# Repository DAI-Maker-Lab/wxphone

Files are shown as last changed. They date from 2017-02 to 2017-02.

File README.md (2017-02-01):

# wxPhone
wxPhone is an open-source weather station design based on the Seeeduino Stalker V3, Adafruit FONA and BME280 breakout boards, and Ambient Data Systems weather meters. It is a work in progress and is presently being field tested in Silver Spring, Maryland in the United States and Malang, Indonesia.

The design will not work with the newer Stalker V3.1 boards; among other issues they do not supply enough current to power the FONA. This is a problem. The next iteration will use a different microcontroller and a configuration that allows the BME280 board to be mounted separately from the other electronics, so that only the BME280 is exposed to the air.

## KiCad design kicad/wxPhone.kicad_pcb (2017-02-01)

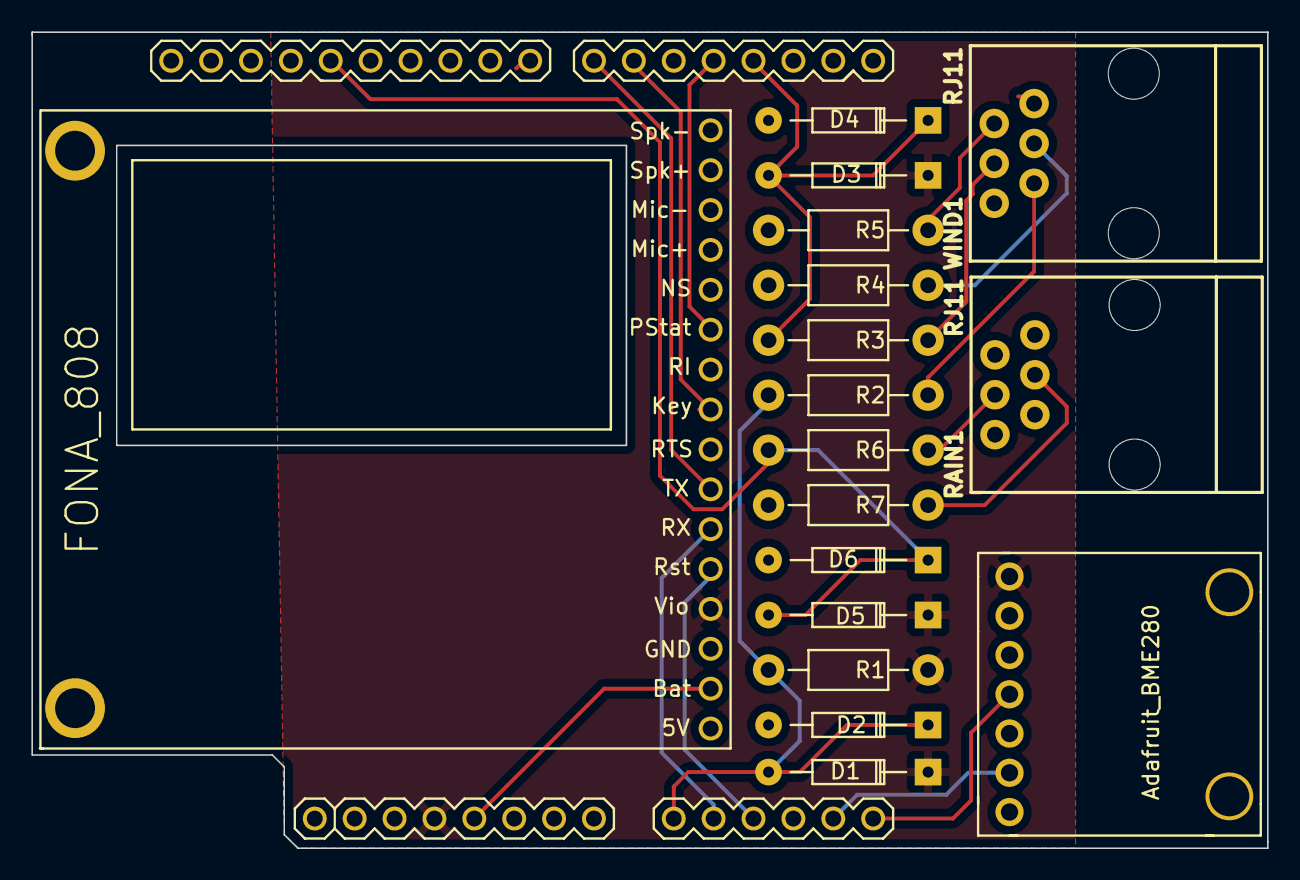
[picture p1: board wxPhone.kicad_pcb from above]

Board: 2 copper layers, 78.7 x 52.0 mm, 18 parts (0 on the bottom side), 19 nets.

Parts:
D1, D2, D3, D4, D5, D6: DIODE; Diode_DO-35_SOD27_Horizontal_RM10
R1: 4.7K; Resistor_Horizontal_RM10mm
R2, R3, R4, R5, R6, R7: 1K; Resistor_Horizontal_RM10mm
RAIN1: RJ11; RJ11-6
SHIELD1: ARDUINO_SHIELD; ARDUINO
U1: Adafruit_BME280
U2: FONA_808
WIND1: RJ11; RJ11-6

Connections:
3V3: D1.K, D3.K, D5.K, R1.1, SHIELD1.3V3, U1.VIN, U2.4
GND: D2.A, D4.A, D6.A, R4.2, R5.2, R7.2, SHIELD1.GND1, U1.GND, U2.3
unnamed: R2.1, WIND1.2
unnamed: R3.1, WIND1.3
unnamed: R4.1, WIND1.4
unnamed: R5.1, WIND1.5
unnamed: R6.1, RAIN1.3
unnamed: R7.1, RAIN1.4
unnamed: SHIELD1.4, U2.11
unnamed: SHIELD1.6, U2.9
unnamed: SHIELD1.7, U2.7
unnamed: SHIELD1.AD4, U1.SDI
unnamed: SHIELD1.AD5, U1.SCK
RAIN: D5.A, D6.K, R6.2, SHIELD1.13
RST: SHIELD1.AD2, U2.5
RX: SHIELD1.AD1, U2.6
VCC+: SHIELD1.5V, U2.2
WDIR: D1.A, D2.K, R1.2, R2.2, SHIELD1.AD0
WSPEED: D3.A, D4.K, R3.2, SHIELD1.3

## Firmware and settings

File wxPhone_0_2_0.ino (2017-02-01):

#define VERSION "0.2.0"      //  Version number

//  Customize these items for each installation
// - - - - - - - - - - - - - - - - - - - - - - - - - - - - - - - - - - - - - - - 
#define PUBLIC_KEY "dZ9j1JqgEwtqp8QGyQLn"      //  Public key for phant stream
#define PRIVATE_KEY "eEJjA1V5XxTD5mlMxl0B"    //  Private key for phant stream
#define INITIAL_LAT 39.020000
#define INITIAL_LON -77.050000
#define INITIAL_ALT 122

#define UTCOFFSET -5        //  Local standard time variance from UTC
#define XBEEWINDOWSTART 8   //  Hour to turn on XBee for programming window
#define XBEEWINDOWEND 20    //  Hour to turn off XBee
#define INTERVAL 15         //  Number of minutes between readings
#define BEEPASSWORD "XBEE_PASSWORD"  //  Password to turn on XBee by SMS
// - - - - - - - - - - - - - - - - - - - - - - - - - - - - - - - - - - - - - - - 



#include <Adafruit_BME280.h>    //  Pressure/temp/humidity sensor
#include <Adafruit_FONA.h>      //  For Adafruit FONA module
#include <Adafruit_Sensor.h>    //  Adafruit unified sensor abstraction layer
#include <DS1337.h>             //  For the Stalker's real-time clock (RTC)
#include <ss_no_int3.h>         //  SoftwareSerial with pin-change conflict removed
#include <Sleep_n0m1.h>         //  Sleep library
#include <SPI.h>
#include <Wire.h>               //  I2C needed for sensors



#define RTCINT 0                //  RTC interrupt number
#define WDIR A0                 //  Wind direction from vane
#define FONA_RX A1              //  FONA RX pin
#define FONA_RST A2             //  FONA reset pin
#define WSPEED 3                //  Wind speed interrupt pin
#define FONA_TX 7               //  FONA TX pin
#define BEEPIN 5                //  XBee power pin
#define FONA_KEY 6              //  FONA on/off pin
#define FONA_PS 4               //  FONA power status pin
#define RAIN 13                 //  Rain gauge interrupt pin

long lastWindCheck = 0;
volatile long lastWindIRQ = 0;
volatile byte windClicks = 0;
volatile float rainMinute[60];      //  60 floating numbers to keep track of 60 minutes of rain

//  Weather values
char* wind_dir;                    //  Instantaneous wind direction
float wind_speed = 0;              //  km/h instantaneous wind speed
float temp = 0;                    //  temperature C
float humidity = 0;                //  %
float pressure = 0;
float rainHourly[24];              //  24 floats to track the last 24 hours of rain
float rain_today = 0.00;           //  Rain since midnight (mm)

volatile unsigned long raintime, rainlast, raininterval, rain;

boolean dataSent = false;

byte beeShutoffHour = 0;        //  Hour to turn off manual power to XBee
byte beeShutoffMinute = 0;      //  Minute to turn off manual power to XBee
boolean smsPower = false;       //  Manual XBee power flag

/* We will create variables to hold  values for the time and date from the RTC. */
int currentHour;    
byte currentMinute;     
byte currentDay;
byte currentMonth;
int currentYear;
DateTime now;

float latitude = INITIAL_LAT;
float longitude = INITIAL_LON;
float altitude = INITIAL_ALT;

ss_no_int3 fonaSerial = ss_no_int3 (FONA_TX, FONA_RX);
Adafruit_FONA fona = Adafruit_FONA (FONA_RST);

Adafruit_BME280 bme;              //  Instantiate BME280 sensor object
DS1337 RTC;                       //  Instantiate real-time clock (RTC) object
Sleep sleep;                      //  Instantiate sleep object



void pciSetup()
{
        //  Setup pin change interrupt for rain pin
        *digitalPinToPCMSK(RAIN) |= bit (digitalPinToPCMSKbit(RAIN));  //   Enable pin
        PCIFR  |= bit (digitalPinToPCICRbit(RAIN)); //    Clear any outstanding interrupt
        PCICR  |= bit (digitalPinToPCICRbit(RAIN)); //    Enable interrupt for the group
}



static void rtcIRQ()
{
        RTC.clearINTStatus();   //  Wake from sleep and clear the RTC interrupt
}



ISR (PCINT0_vect)                    //  Count rain gauge bucket tips as they occur
{
        raintime = millis();       
        raininterval = raintime - rainlast;  //  calculate interval between this and last event
      
        if (raininterval > 40)  //  ignore switch-bounce glitches less than 10mS after initial edge
        {
                rain_today += 0.2794;                //  Each dump is 0.2794mm of water
                rainMinute[currentMinute] += 0.2794; //  Increase this minute's amount of rain
                rainlast = raintime;                 //  Set up for next event
        }
}



static void wspeedIRQ()      //  Activated by the magnet in the anemometer (2 ticks per rotation)
{
        if (millis() - lastWindIRQ > 10)  //  Ignore switch-bounce glitches less than 10ms
        {
                lastWindIRQ = millis();   
                windClicks++;             //  Each click per second represents 2.40264 km/h of wind
        }
}



void setup()
{
        Wire.begin(); //  Begin the I2C interface
        RTC.begin();  //  Begin the RTC        
        Serial.begin (57600);
        Serial.print (F("wxPhone version "));
        Serial.print (VERSION);
        Serial.print (F(" "));
        Serial.print (__DATE__);    //  Compile data and time helps identify software uploads
        Serial.print (F(" "));
        Serial.println (__TIME__);

        analogReference (INTERNAL); 

        Serial.print (F("Startup voltage "));
        Serial.println (analogRead (A7) * 6.4);   //  Convert ADC reading to voltage
        
        pinMode (BEEPIN, OUTPUT);
        pinMode (FONA_KEY, OUTPUT);
        pinMode (FONA_PS, INPUT);       
        pinMode (FONA_RX, OUTPUT);
        pinMode (WSPEED, INPUT_PULLUP);
        pinMode (RAIN, INPUT_PULLUP);
        pinMode (WDIR, INPUT);


        /*   If the voltage at startup is less than 3.5V, we assume the battery died in the field
         *   and the unit is attempting to restart after the panel charged the battery enough to
         *   do so. However, running the unit with a low charge is likely to just discharge the
         *   battery again, and we will never get enough charge to resume operation. So while the
         *   measured voltage is less than 3.5V, we will put the unit to sleep and wake once per 
         *   hour to check the charge status.
         */

        while (analogRead (A7) < 547)   
        {
                Serial.print (F("Battery voltage is only "));
                Serial.print (analogRead (A7) * 6.4);
                Serial.print (F("mV. Sleeping to save power while panel recharges..."));
                Serial.flush();
                digitalWrite (BEEPIN, HIGH);      //  Make sure XBee is powered off
                RTC.enableInterrupts (EveryHour); //  We'll wake up once an hour
                RTC.clearINTStatus();             //  Clear any outstanding interrupts
                attachInterrupt (RTCINT, rtcIRQ, FALLING);
                interrupts();
                sleep.pwrDownMode();                    //  Set sleep mode to Power Down
                sleep.sleepInterrupt (RTCINT, FALLING); //  Sleep; wake on falling voltage on RTC pin
        }

        digitalWrite (FONA_KEY, HIGH);       //  Initial state for key pin

        //  We will use the FONA to get the current time to set the Stalker's RTC
        fonaOn();
        clockSet();
        
        //  Delete any accumulated SMS messages to avoid interference from old commands
        fona.sendCheckReply (F("AT+CMGF=1"), F("OK"));            //  Enter text mode
        fona.sendCheckReply (F("AT+CMGDA=\"DEL ALL\""), F("OK")); //  Delete all SMS messages

        gpsFix();
        
        fonaOff();

        pciSetup();
        RTC.enableInterrupts (EveryMinute);  //  RTC will interrupt every minute
        RTC.clearINTStatus();                //  Clear any outstanding interrupts
        attachInterrupt (RTCINT, rtcIRQ, FALLING);

        now = RTC.now();    //  Get the current time from the RTC
        
        //  We'll keep the XBee on for an hour after startup to assist installation
        if (now.hour() == 23)
        {
                beeShutoffHour = 0;
        }
        else
        {
                beeShutoffHour = (now.hour() + 1);
        }
        beeShutoffMinute = now.minute();

        Serial.print (F("XBee powered on until at least "));
        Serial.print (beeShutoffHour);
        Serial.print (F(":"));
        Serial.println (beeShutoffMinute);
        Serial.flush();
        smsPower = true; 
        
        if (bme.begin() == false) 
        {
                Serial.println(F("Could not find a valid BME280 sensor; check wiring."));
                while (1);
        }
        else
        {
                Serial.print (F("Humidity: "));
                Serial.println (bme.readHumidity());
                Serial.print (F("Local pressure: "));
                Serial.println (bme.readPressure() / 100);
                Serial.print (F("Sea level pressure: "));
                getPressure();
                Serial.println (pressure);
                Serial.print (F("Temperature: "));
                Serial.println (bme.readTemperature());
        }

        analogReference (DEFAULT);
      
        // attach external interrupt pins to IRQ functions
        //attachInterrupt(0, rainIRQ, FALLING);
        attachInterrupt(1, wspeedIRQ, FALLING);
      
        interrupts();      
}



void loop()
{
        now = RTC.now();   //  Get the current date/time
        
        if(currentMinute != now.minute())
        {
                currentMinute = now.minute(); 
                rainMinute[currentMinute] = 0; 
                
                if(currentMinute == 0)    //  Every hour, update the hourly rain count
                {
                        int lastHour;
                        currentHour = now.hour();
                        
                        if(currentHour == 0)
                        {
                                lastHour = 23;
                        }
                        else
                        {
                                lastHour = currentHour - 1;
                        }
                        
                        rainHourly[lastHour] = 0;
                        
                        for(int i = 0 ; i < 60 ; i++)
                        {
                                rainHourly[lastHour] += rainMinute[i];
                        }
                }
        }

        //  We will turn on the XBee radio for programming only within a specific
        //  window to save power
        if (now.hour() >= XBEEWINDOWSTART && now.hour() <= XBEEWINDOWEND)
        {
                digitalWrite (BEEPIN, LOW);
        }
        else
        {
                //  If the XBee power was turned on by SMS, we'll check to see if 
                //  it's time to turn it back off
                if(smsPower == true && now.hour() < beeShutoffHour)
                {
                        digitalWrite (BEEPIN, LOW);
                }
                else
                {
                        if(smsPower == true && now.hour() == beeShutoffHour && now.minute() < beeShutoffMinute)
                        {
                                digitalWrite (BEEPIN, LOW);
                        }
                        else
                        {
                                if (smsPower == true)
                                {
                                          Serial.println (F("Turning XBee off..."));
                                          Serial.flush();
                                          wait (500);
                                }

                                digitalWrite (BEEPIN, HIGH);
                                smsPower = false;
                        }
                }
        }

        //  If the sent flag is up and this is not an upload minute, lower it
        if(currentMinute % INTERVAL != 0 && dataSent == true)  
        {
                dataSent = false;
        }
        
        //  Check to see if upload is necessary; if so, take readings and send them
        if(currentMinute % INTERVAL == 0 && dataSent == false)
        {       
                Serial.println(F("Upload minute; will boot FONA."));
  
                currentHour = now.hour();      
                currentDay = now.date();       
                currentMonth = now.month();
                currentYear = now.year();
        
                calcWeather();  //  Poll the various sensors
        
                fonaOn();     //  Start the Fona
        
                //  We will attempt to upload data to the cloud. If the attempt fails,
                //  we will restart the Fona and try again for up to three attempts.
            
                byte sendAttempts = 0;    //  Reset the counter
            
                while(dataSent == false && sendAttempts <= 2)
                {
                        sendAttempts++;   //  Increment attempt counter
                  
                        if(sendWeather() == false)  //  If upload appears to fail...
                        {
                                Serial.println(F("Upload failed. Restarting Fona."));
                                fonaOff();   //  ...shut the FONA off.
                                delay(5000);      //  Give the FONA a moment
                                fonaOn();         //  Reboot.
                                dataSent = false; //  Ensure flag is down
                        }
                        else
                        {
                                dataSent = true;
                        }
                }
        
                if(currentHour == 0 && currentMinute == 0)  //  At midnight, after upload...
                {
                        rain_today = 0.00;       // ...zero out the day's rain total...
                        clockSet();              // ...and set the time again -- the RTC loses about
                                                 // one minute every six days.
                        if (latitude == INITIAL_LAT)  //  If we never successfully got a GPS fix...
                        {
                                gpsFix();             //  ...try again.
                        }
                }

                fonaOff();           //  Shut down the FONA to save power
        }

        sleep.pwrDownMode();                    //  Set sleep mode to Power Down
        sleep.sleepInterrupt (RTCINT, FALLING); //  Sleep; wake on falling voltage on RTC pin
}



void wait (unsigned long period)
{
        //  Non-blocking delay function
        unsigned long waitend = millis() + period;
        while (millis() <= waitend)
        {
                Serial.flush();
        }
}



boolean fonaOn()
{
        if (digitalRead (FONA_PS) == LOW)             //  If the FONA is off...
        {
                Serial.print (F("Powering FONA on..."));
                while (digitalRead (FONA_PS) == LOW) 
                {
                        digitalWrite(FONA_KEY, LOW);  //  ...pulse the Key pin low...
                        wait (500);
                }
                digitalWrite (FONA_KEY, HIGH);        //  ...and then return it to high
                Serial.println(F(" done."));
        }
        
        Serial.println (F("Initializing FONA..."));
        
        fonaSerial.begin (4800);                      //  Open a serial interface to FONA
        
        if (fona.begin (fonaSerial) == false)         //  Start the FONA on serial interface
        {
                Serial.println (F("FONA not found. Check wiring and power."));
                return false;
        }
        else
        {
                Serial.print (F("FONA online. "));
                
                unsigned long gsmTimeout = millis() + 30000;
                boolean gsmTimedOut = false;

                Serial.print (F("Waiting for GSM network... "));
                while (1)
                {
                        byte network_status = fona.getNetworkStatus();
                        if(network_status == 1 || network_status == 5) break;
                        
                        if(millis() >= gsmTimeout)
                        {
                                gsmTimedOut = true;
                                break;
                        }
                        
                        wait (250);
                }

                if(gsmTimedOut == true)
                {
                        Serial.println (F("timed out. Check SIM card, antenna, and signal."));
                        return false;
                }
                else
                {
                        Serial.println(F("done."));
                }

                //  RSSI is a measure of signal strength -- higher is better; less than 10 is worrying
                byte rssi = fona.getRSSI();
                Serial.print (F("RSSI: "));
                Serial.println (rssi);

                wait (3000);    //  Give the network a moment

                //fona.setGPRSNetworkSettings (F("cellcard"));    //  Set APN to your local carrier

                if (rssi > 5)
                {
                        if (fona.enableGPRS (true) == false);
                        {
                              //  Sometimes enableGPRS() returns false even though it succeeded
                              if (fona.GPRSstate() != 1)
                              {
                                      for (byte GPRSattempts = 0; GPRSattempts < 5; GPRSattempts++)
                                      {
                                            Serial.println (F("Trying again..."));
                                            wait (2000);
                                            fona.enableGPRS (true);
                                            
                                            if (fona.GPRSstate() == 1)
                                            {
                                                    Serial.println (F("GPRS is on."));
                                                    break;
                                            }
                                            else
                                            {
                                                    Serial.print (F("Failed to turn GPRS on... "));
                                            }
                                      }
                              }
                        }
                }
                else
                {
                        Serial.println (F("Can't transmit, network signal strength is poor."));
                        gsmTimedOut = true;
                }
                
                return true;
        }
}
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

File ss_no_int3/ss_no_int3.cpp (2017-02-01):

/*
ss_no_int3.cpp (formerly NewSoftSerial.cpp) - 
Multi-instance software serial library for Arduino/Wiring
-- Interrupt-driven receive and other improvements by ladyada
   (http://ladyada.net)
-- Tuning, circular buffer, derivation from class Print/Stream,
   multi-instance support, porting to 8MHz processors,
   various optimizations, PROGMEM delay tables, inverse logic and 
   direct port writing by Mikal Hart (http://www.arduiniana.org)
-- Pin change interrupt macros by Paul Stoffregen (http://www.pjrc.com)
-- 20MHz processor support by Garrett Mace (http://www.macetech.com)
-- ATmega1280/2560 support by Brett Hagman (http://www.roguerobotics.com/)

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
The latest version of this library can always be found at
http://arduiniana.org.
*/

// When set, _DEBUG co-opts pins 11 and 13 for debugging with an
// oscilloscope or logic analyzer.  Beware: it also slightly modifies
// the bit times, so don't rely on it too much at high baud rates
#define _DEBUG 0
#define _DEBUG_PIN1 11
#define _DEBUG_PIN2 13
// 
// Includes
// 
#include <avr/interrupt.h>
#include <avr/pgmspace.h>
#include <Arduino.h>
#include <ss_no_int3.h>
#include <util/delay_basic.h>

//
// Statics
//
ss_no_int3 *ss_no_int3::active_object = 0;
uint8_t ss_no_int3::_receive_buffer[_SS_MAX_RX_BUFF]; 
volatile uint8_t ss_no_int3::_receive_buffer_tail = 0;
volatile uint8_t ss_no_int3::_receive_buffer_head = 0;

//
// Debugging
//
// This function generates a brief pulse
// for debugging or measuring on an oscilloscope.
#if _DEBUG
inline void DebugPulse(uint8_t pin, uint8_t count)
{
  volatile uint8_t *pport = portOutputRegister(digitalPinToPort(pin));

  uint8_t val = *pport;
  while (count--)
  {
    *pport = val | digitalPinToBitMask(pin);
    *pport = val;
  }
}
#else
inline void DebugPulse(uint8_t, uint8_t) {}
#endif

//
// Private methods
//

/* static */ 
inline void ss_no_int3::tunedDelay(uint16_t delay) { 
  _delay_loop_2(delay);
}

// This function sets the current object as the "listening"
// one and returns true if it replaces another 
bool ss_no_int3::listen()
{
  if (!_rx_delay_stopbit)
    return false;

  if (active_object != this)
  {
    if (active_object)
      active_object->stopListening();

    _buffer_overflow = false;
    _receive_buffer_head = _receive_buffer_tail = 0;
    active_object = this;

    setRxIntMsk(true);
    return true;
  }

  return false;
}

// Stop listening. Returns true if we were actually listening.
bool ss_no_int3::stopListening()
{
  if (active_object == this)
  {
    setRxIntMsk(false);
    active_object = NULL;
    return true;
  }
  return false;
}

//
// The receive routine called by the interrupt handler
//
void ss_no_int3::recv()
{

#if GCC_VERSION < 40302
// Work-around for avr-gcc 4.3.0 OSX version bug
// Preserve the registers that the compiler misses
// (courtesy of Arduino forum user *etracer*)
  asm volatile(
    "push r18 \n\t"
    "push r19 \n\t"
    "push r20 \n\t"
    "push r21 \n\t"
    "push r22 \n\t"
    "push r23 \n\t"
    "push r26 \n\t"
    "push r27 \n\t"
    ::);
#endif  

  uint8_t d = 0;

  // If RX line is high, then we don't see any start bit
  // so interrupt is probably not for us
  if (_inverse_logic ? rx_pin_read() : !rx_pin_read())
  {
    // Disable further interrupts during reception, this prevents
    // triggering another interrupt directly after we return, which can
    // cause problems at higher baudrates.
    setRxIntMsk(false);

    // Wait approximately 1/2 of a bit width to "center" the sample
    tunedDelay(_rx_delay_centering);
    DebugPulse(_DEBUG_PIN2, 1);

    // Read each of the 8 bits
    for (uint8_t i=8; i > 0; --i)
    {
      tunedDelay(_rx_delay_intrabit);
      d >>= 1;
      DebugPulse(_DEBUG_PIN2, 1);
      if (rx_pin_read())
        d |= 0x80;
    }

    if (_inverse_logic)
      d = ~d;

    // if buffer full, set the overflow flag and return
    uint8_t next = (_receive_buffer_tail + 1) % _SS_MAX_RX_BUFF;
    if (next != _receive_buffer_head)
    {
      // save new data in buffer: tail points to where byte goes
      _receive_buffer[_receive_buffer_tail] = d; // save new byte
      _receive_buffer_tail = next;
    } 
    else 
    {
      DebugPulse(_DEBUG_PIN1, 1);
      _buffer_overflow = true;
    }

    // skip the stop bit
    tunedDelay(_rx_delay_stopbit);
    DebugPulse(_DEBUG_PIN1, 1);

    // Re-enable interrupts when we're sure to be inside the stop bit
    setRxIntMsk(true);

  }

#if GCC_VERSION < 40302
// Work-around for avr-gcc 4.3.0 OSX version bug
// Restore the registers that the compiler misses
  asm volatile(
    "pop r27 \n\t"
    "pop r26 \n\t"
    "pop r23 \n\t"
    "pop r22 \n\t"
    "pop r21 \n\t"
    "pop r20 \n\t"
    "pop r19 \n\t"
    "pop r18 \n\t"
    ::);
#endif
}

uint8_t ss_no_int3::rx_pin_read()
{
  return *_receivePortRegister & _receiveBitMask;
}

//
// Interrupt handling
//

/* static */
inline void ss_no_int3::handle_interrupt()
{
  if (active_object)
  {
    active_object->recv();
  }
}

#if defined(PCINT0_vect)
ISR(PCINT0_vect)
{
  ss_no_int3::handle_interrupt();
}
#endif

#if defined(PCINT1_vect)
ISR(PCINT1_vect, ISR_ALIASOF(PCINT0_vect));
#endif

#if defined(PCINT2_vect)
ISR(PCINT2_vect, ISR_ALIASOF(PCINT0_vect));
#endif

//#if defined(PCINT3_vect)
//ISR(PCINT3_vect, ISR_ALIASOF(PCINT0_vect));
//#endif

//
// Constructor
//
ss_no_int3::ss_no_int3(uint8_t receivePin, uint8_t transmitPin, bool inverse_logic /* = false */) : 
  _rx_delay_centering(0),
  _rx_delay_intrabit(0),
  _rx_delay_stopbit(0),
  _tx_delay(0),
  _buffer_overflow(false),
  _inverse_logic(inverse_logic)
{
  setTX(transmitPin);
  setRX(receivePin);
}

//
// Destructor
//
ss_no_int3::~ss_no_int3()
{
  end();
}

void ss_no_int3::setTX(uint8_t tx)
{
  // First write, then set output. If we do this the other way around,
  // the pin would be output low for a short while before switching to
  // output high. Now, it is input with pullup for a short while, which
  // is fine. With inverse logic, either order is fine.
  digitalWrite(tx, _inverse_logic ? LOW : HIGH);
  pinMode(tx, OUTPUT);
  _transmitBitMask = digitalPinToBitMask(tx);
  uint8_t port = digitalPinToPort(tx);
  _transmitPortRegister = portOutputRegister(port);
}

void ss_no_int3::setRX(uint8_t rx)
{
  pinMode(rx, INPUT);
  if (!_inverse_logic)
    digitalWrite(rx, HIGH);  // pullup for normal logic!
  _receivePin = rx;
  _receiveBitMask = digitalPinToBitMask(rx);
  uint8_t port = digitalPinToPort(rx);
  _receivePortRegister = portInputRegister(port);
}

uint16_t ss_no_int3::subtract_cap(uint16_t num, uint16_t sub) {
  if (num > sub)
    return num - sub;
  else
    return 1;
}

//
// Public methods
//
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
